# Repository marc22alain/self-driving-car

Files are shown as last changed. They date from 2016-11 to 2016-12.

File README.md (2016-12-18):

# self-driving-car

## Purpose:
A lab project for CSC-385:to build and program an autonomous vehicle capable of driving around the central pod of desks in the lab room BA 3165.

## Software design:

We implemented a state machine to govern the car's behaviour.
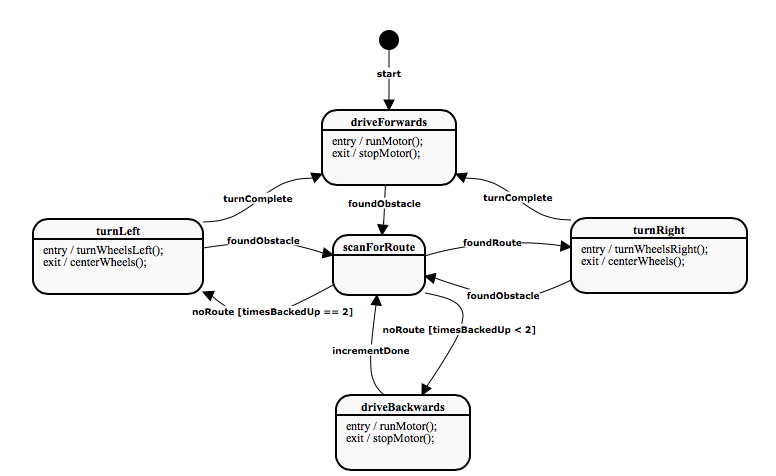
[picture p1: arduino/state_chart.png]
image of state chart


## Hardware design:

The microcontroller is an ATMega 328P (Arduino UNO). The additional devices are:
- sonar rangefinder MaxSonar 1010
- magnetometer HMC5883L
- two servos Fitec FS90; one for steering, the other to orient the rangefinder
- one H-bridge motor driver L9110
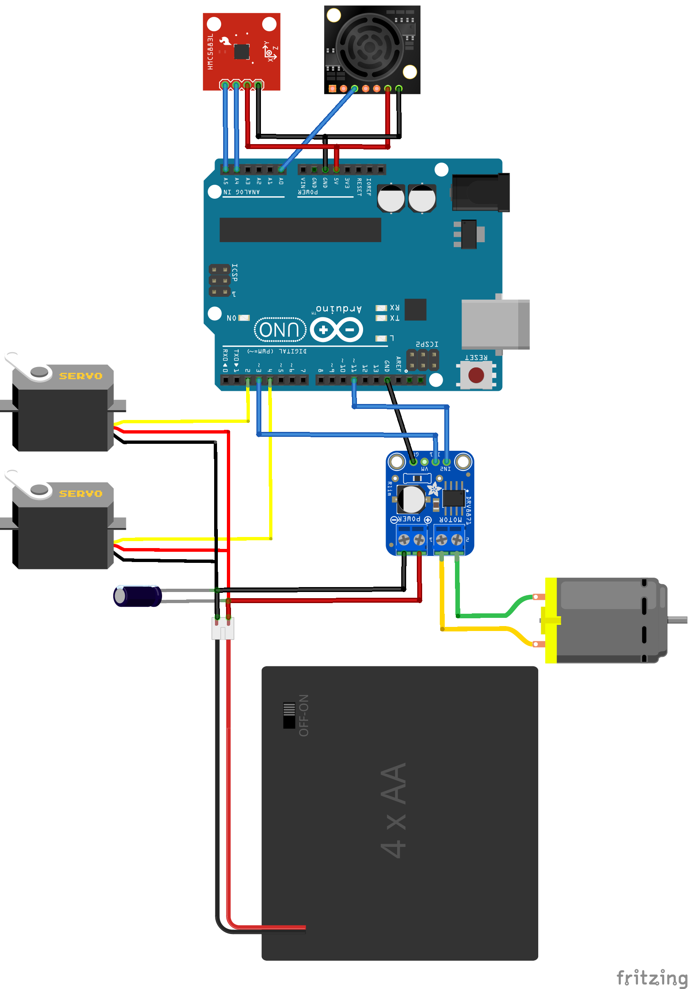
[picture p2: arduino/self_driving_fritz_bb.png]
image of block diagram


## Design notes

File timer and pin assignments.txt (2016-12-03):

device:				pin:
——————————————————————————————————

steering servo			2
range-finding servo		4

i2c SCL				A5
12c SDA				A4

range finder			A0

motor driver forward - PWM	11
motor driver backward - PWM	3

timers:		functions:		pins served:
____________________________________________________

timer0		delay(), millis()	any

timer1		Servo			any

timer2		8-bit PWM		3, 11

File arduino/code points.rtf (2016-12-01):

points:

- “speed” constant is established with sufficient power to drive the car
. own experiments show that power needs to be at least 50%

- void checkTurn (int cur_heading, int targ_heading)
.it’s also Boolean, not Void
.we want it to return True when heading is approximately correct
.we may also need it to be smart about an over-turn situation
.we also want it to be smart about 359° vs 0°

more tbd…

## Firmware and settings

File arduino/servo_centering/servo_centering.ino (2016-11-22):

/* Sweep
 by BARRAGAN <http://barraganstudio.com>
 This example code is in the public domain.

 modified 8 Nov 2013
 by Scott Fitzgerald
 http://www.arduino.cc/en/Tutorial/Sweep
*/

#include <Servo.h>
#define steering_servo_pin 2
#define ranging_servo_pin 4

Servo steering_servo;  // create servo object to control a servo
Servo ranging_servo;  // create servo object to control a servo
// twelve servo objects can be created on most boards

/*
 * NB: the steering servo is physically range-restricted
 *     to 20 - 180 degrees
 */
int pos = 0;    // variable to store the servo position


void setup() {
  steering_servo.attach(steering_servo_pin);
  ranging_servo.attach(ranging_servo_pin);
  steering_servo.write(90);              // tell servo to go to centered position
  ranging_servo.write(90);              // tell servo to go to centered position
  delay(10000);
    for (pos = 90; pos >= 20; pos -= 1) { // goes from centered position to 0 degrees
    steering_servo.write(pos);              // tell servo to go to position in variable 'pos'
    ranging_servo.write(pos);              // tell servo to go to position in variable 'pos'
    delay(5);                       // waits 15ms for the servo to reach the position
  }

}

void loop() {
//  for (pos = 20; pos <= 180; pos += 1) { // goes from 0 degrees to 180 degrees
//    // in steps of 1 degree
//    steering_servo.write(pos);              // tell servo to go to position in variable 'pos'
//    delay(15);                       // waits 15ms for the servo to reach the position
//  }
//  for (pos = 180; pos >= 20; pos -= 1) { // goes from 180 degrees to 0 degrees
//    steering_servo.write(pos);              // tell servo to go to position in variable 'pos'
//    delay(15);                       // waits 15ms for the servo to reach the position
//  }
//  for (pos = 0; pos <= 180; pos += 1) { // goes from 0 degrees to 180 degrees
//    // in steps of 1 degree
//    ranging_servo.write(pos);              // tell servo to go to position in variable 'pos'
//    delay(15);                       // waits 15ms for the servo to reach the position
//  }
//  for (pos = 180; pos >= 0; pos -= 1) { // goes from 180 degrees to 0 degrees
//    ranging_servo.write(pos);              // tell servo to go to position in variable 'pos'
//    delay(15);                       // waits 15ms for the servo to reach the position
//  }

}

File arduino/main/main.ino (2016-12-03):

#include <Servo.h>
#include <Wire.h>
#include <HMC5883L.h>

#define steering_servo_pin 2
#define ranging_servo_pin 4
#define setup_LED_pin 13

#define STOP 0

Servo steering_servo;  // create servo object to control a servo
// create a servo object to control a the range finder servo
Servo ranging_servo;  

HMC5883L compass;

int Offset_x  = 154.80; // mG
int Offset_y  = 266.58; // mG
int Offset_z  = 343.81; // mG


// Define a few GLOBAL VARIABLES
// we may want an interface to adjust these at the device,
// to save continually reprogramming the Arduino
int distance_threshold = 45;
int turn_distance_threshold = 30;
int speed = 130;
int turnSpeed = 170;
int currentSpeed = 0;           // stores the car's current speed
int rangefinder_servo_pos = 0;  // stores the rangefinder servo's current position
int steer_servo_pos = 0;        // stores the steering servo's current position

int timesBackedUp = 0;

void setup() {
  
  steering_servo.attach(steering_servo_pin);
  ranging_servo.attach(ranging_servo_pin);
  centerWheels();
  centerRangeFinder();

  Wire.begin();
  compass = HMC5883L();
  compass.SetMeasurementMode(Measurement_Continuous);
  compass.SetMeasurementRate(Hz75);

  Serial.begin(9600);
  // turn on the setup indicator LED
  // and wait 10 seconds to set up the car
  pinMode(setup_LED_pin, OUTPUT);
  digitalWrite(setup_LED_pin, HIGH);
  delay(10000);
  digitalWrite(setup_LED_pin, LOW);

}

void loop() {
  // this is the initial state
  driveForwards();

}

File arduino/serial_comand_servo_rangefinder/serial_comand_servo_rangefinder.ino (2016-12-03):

/* Requires: - serial port already open
 *           - serial message terminated with a new line character
 *
 * Ensures:  - returns an intenger value (possibly negative)
 */
int parseForNumber () {
  // loop guard
  bool done = false;
  bool negative = false;
  int command = 0;
  while (!done) {
    // busy waiting until another char arrives
    if (Serial.available()) {
      
      char letter = Serial.read();
      
      // first check for a negative sign
      // note that this allows the user to type the sign
      // anywhere in their input
      if (letter == '-') {
        negative = true;
      }
      
      // otherwise check if it's a number 
      else if (letter >= '0' && letter <= '9') {
        // clever conversion from char to int
        int digit = letter - '0';
        // shift the currently stored number one decimal place
        command *= 10;
        // now add the new digit to the number
        command += digit;
      }

      // otherwise check if it's the end of the command
      else if (letter = '\n') {
        done = true;
      }

      // otherwise user made a mistake
      else {
        // do nothing, ignore this letter
      }
    }
  }

  // now that command input is complete, apply the sign
  if (negative) {
    command *= -1;
  }

  return command;
}

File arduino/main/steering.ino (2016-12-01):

/* Device-specific functions for the steering servo
 * NB: the steering servo is physically range-restricted
 *     to 20 - 180 degrees
 */
int default_steer_servo_pos = 90;    // variable to store the servo position

int rangefinder_servo_default_pos = 90;


void centerWheels () {
  steer_servo_pos = default_steer_servo_pos;
  steering_servo.write(steer_servo_pos);
}

/*
 * This function is used in the turn state to make a turn the vehicle towards
 * the right heading
 */
void turnWheelsRight(){
  steer_servo_pos = 10;
  steering_servo.write(steer_servo_pos);
}

/*
 * This function is used in the turn state to make a turn the vehicle towards
 * the right heading
 */
void turnWheelsLeft(){
  steer_servo_pos = 170;
  steering_servo.write(steer_servo_pos);
}

/*
 * This function turns the range finder servo 10 degrees to the right,
 * reading from the range finder after each turn. 
 * It returns the reading from the range finder after a turn
 */
void turnRangefinder() {
  rangefinder_servo_pos -= 10;
  if(rangefinder_servo_pos == -10){
    return;
  }
  ranging_servo.write(rangefinder_servo_pos);
}

void centerRangeFinder () {
  rangefinder_servo_pos = rangefinder_servo_default_pos;
  ranging_servo.write(rangefinder_servo_pos);
}

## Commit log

2016-11-18 First commit of Arduino code
2016-11-18 Adding the Arduino pin assignments
2016-11-19 Revision to reflect actual range of motion for steering servo
    There is a physical restriction preventing motion within the 0 - 19
    degree range.
    [servo_centering.ino]
2016-11-20 Creating a test configuration
    To test driving straight, detecting an obstacle, then backing up a
    little ways … then repeating.
2016-11-21 Changed pin assignments to resolve timer conflicts
    The Servo library uses Timer1, which then disables PWM on pins 9 & 10.
    This leaves Timer2’s pins 3 & 11 available for the motor driver.
2016-11-23 Updated steering algorithm to accelerate response
    And a little refactoring and bug squishing.
    [main.ino, scanForRoute.ino, steering.ino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]
2016-11-25 Adding assertions on wheel position on entry to driving states.
2016-11-25 Fixing bigs with braking
    [driveBackwards.ino, driveForwards.ino]
2016-11-25 Establish an initial power boost to overcome inertia.
2016-11-25 Fixing bug for wrong direction braking
    [turn.ino]
2016-11-25 Reducing the backup distance; typo fix
    [driveBackwards.ino, turn.ino]
2016-11-25 Collecting multiple samples from the rangefinder now.
2016-12-03 Adding: slow cruising to driveForwards; bug fix in turnLeft; serial prints for each state
    [driveBackwards.ino, driveForwards.ino, main.ino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]
2016-12-03 Updating the pin and timer assignments doc
2016-12-03 Adding serial servo control sketch; new sketch for testing the compass with the HMC5883L library
2016-12-18 Adding the Fritzing diagram
    [self_driving_fritz.fzz]
